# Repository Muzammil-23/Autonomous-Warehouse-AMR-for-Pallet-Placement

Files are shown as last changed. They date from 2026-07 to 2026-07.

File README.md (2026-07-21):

# Autonomous Mobile Robot with Pallet Placement System

## 📋 Project Overview

This project is a complete autonomous robot system designed for precision navigation and material handling. The robot navigates a 4×4 grid using an 8-channel QTR sensor array, detects intersections, and executes complex maneuvers including turning, obstacle detection, and automated pallet placement.

Developed for National Engineering and Robotics Contest (NERC) in 2026, this robot demonstrates:
- Autonomous navigation on grid-based paths
- Precision obstacle detection and avoidance
- Automated pallet placement using color sensing

### 🎯 Key Capabilities

- **Autonomous Navigation:** PID-controlled line following with intersection detection
- **Grid Navigation:** Navigates through intersections with specific turn logic
- **Obstacle Detection:** Ultrasonic sensor for rack detection and collision avoidance
- **Pallet Mechanism:** Servo-controlled pushing/retracting with stepper elevator
- **Color Detection:** TCS34725 sensor for blue color identification during pallet placement
- **State Management:** Multi-phase operation with graceful transitions

## Robot Photos
| Front View | Side View | 
|---|---|
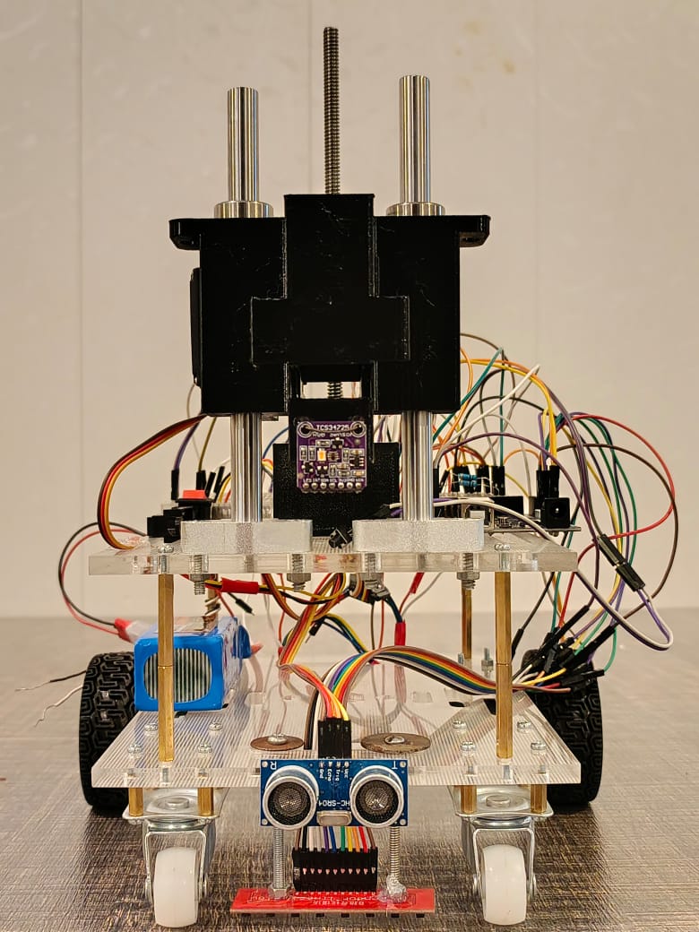
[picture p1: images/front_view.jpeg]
Front
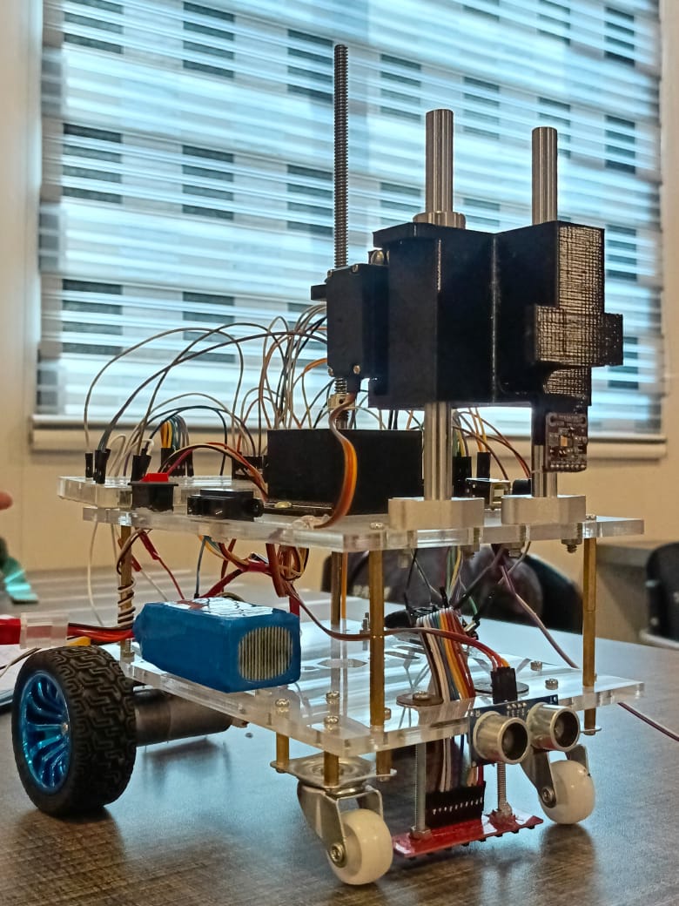
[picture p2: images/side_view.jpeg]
Side
|  |  |

### 🏗️ System Architecture
Phase 1: Grid Navigation 
Navigates the arena autonomously.

Phase 2: Rack Approach
└── Ultrasonic distance monitoring (stops at 1cm)

Phase 3: Pallet Placement
├── Elevator up while scanning for blue color
├── One full rotation after detection
├── Servo pushes pallet (CW)
├── Servo retracts (CCW)
└── Elevator lowers (5500 steps)

### 🔧 Hardware Components

| Component | Purpose | Quantity |
|---|---|---|
| Arduino Mega | Main controller | 1 |
| TB6612FNG | DC motor control | 1 |
| 2x DC Motors | Differential drive | 2 |
| 8-Channel QTR Array | Line sensing | 1 |
| HC-SR04 | Ultrasonic obstacle detection | 1 |
| TCS34725 | Color sensing (blue detection) | 1 |
| NEMA 11 | Elevator mechanism | 1 |
| MG996R | Pallet push/retract | 1 |
| Push Buttons (x2) | Calibration & Start | 2 |

## Assembled robot in SolidWorks
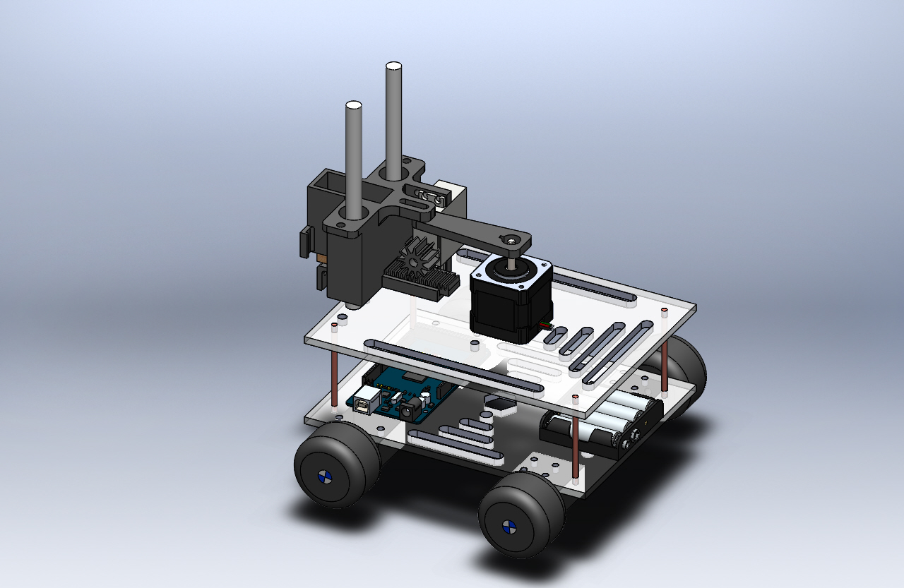
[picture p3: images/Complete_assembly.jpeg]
Assembled robot in Solidworks


### 📦 Required Libraries
```cpp
// Install these libraries from Arduino Library Manager or GitHub
#include <QTRSensors.h>          // Pololu QTR Sensors
#include <SparkFun_TB6612.h>    // TB6612 Motor Driver
#include <Wire.h>               // I2C Communication
#include <Adafruit_TCS34725.h>  // Color Sensor
#include <Servo.h>              // Servo Control

🚀 Getting Started
1. Wiring
Connect components according to the pin configuration in the code:

| Component | Pin(s) |
|-----------|--------|
| TB6612 - AIN1 | 3 |
| TB6612 - AIN2 | 4 |
| TB6612 - PWMA | 5 |
| TB6612 - BIN1 | 7 |
| TB6612 - BIN2 | 8 |
| TB6612 - PWMB | 6 |
| TB6612 - STBY | 9 |
| Ultrasonic TRIG | 18 |
| Ultrasonic ECHO | 19 |
| A4988 STEP | 13 |
| A4988 DIR | 12 |
| Servo | 44 |
| Calibrate Button | 11 |
| Start Button | 10 |
| QTR Sensors | A0-A7 |
| TCS34725 | I2C (SDA/SCL) |
| LED_BUILTIN | 13 |

2. Calibration
Place robot on the line track

Press the calibrate button (Pin 11)

Move robot back and forth over the line during calibration

Wait for LED to stop flashing

3. Running
Press the start button (Pin 10)

Robot will begin autonomous navigation

Monitor Serial Monitor for debug output (9600 baud)

📊 Performance Results

✅ 10/10 successful runs

✅ Consistent intersection detection

✅ ±1cm stopping accuracy from obstacle

✅ Consistent blue color detection and pallet placement

✅ Average completion time: 41 seconds

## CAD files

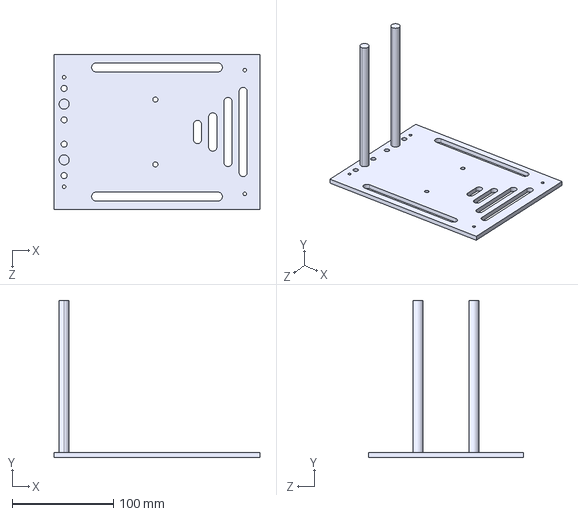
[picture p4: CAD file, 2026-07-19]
CAD Files/Upper_Base.STEP
203.2 x 155.0 x 152.4 mm

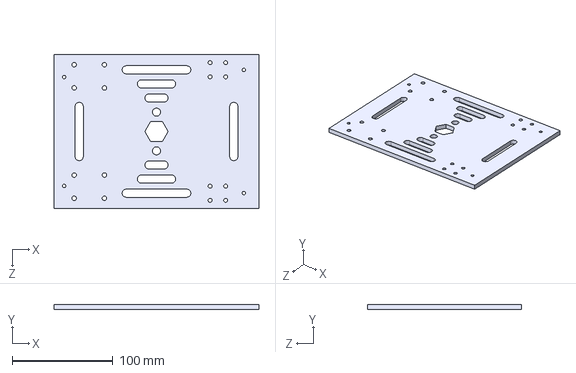
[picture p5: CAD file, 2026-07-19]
CAD Files/Lower_Base.STEP
203.2 x 5.00 x 152.4 mm

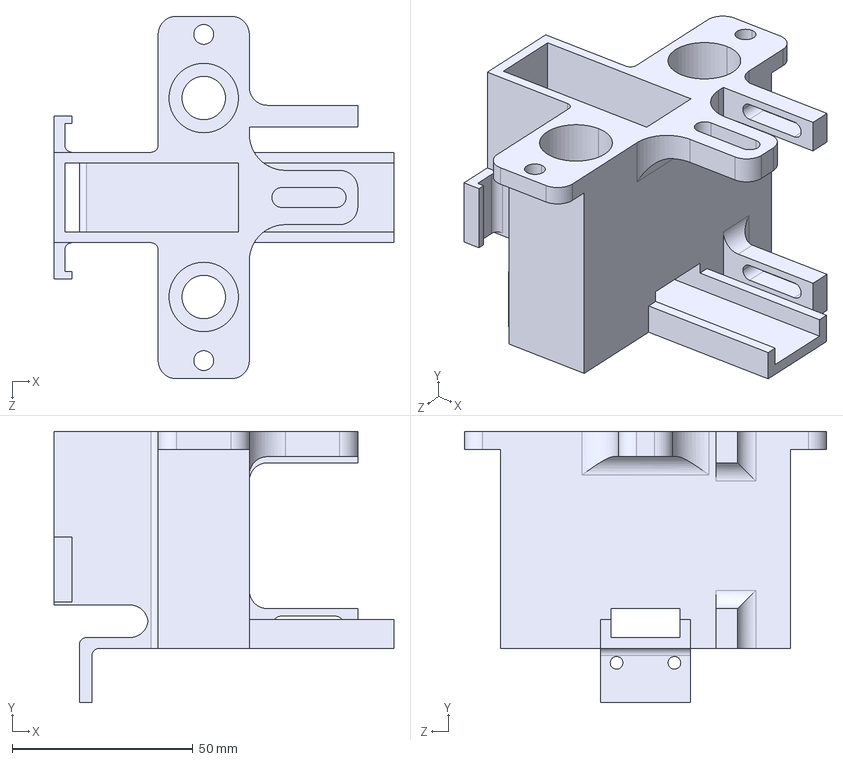
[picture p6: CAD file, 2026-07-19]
CAD Files/Lift_mechanism.STEP
94.0 x 75.0 x 100.2 mm

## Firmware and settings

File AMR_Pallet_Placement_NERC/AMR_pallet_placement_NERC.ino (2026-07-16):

#include <QTRSensors.h>
#include <SparkFun_TB6612.h>
#include <Wire.h>
#include <Adafruit_TCS34725.h>
#include <Servo.h>

// ==================== MOTOR DRIVER PINS ====================
#define AIN1 3
#define AIN2 4
#define PWMA 5
#define BIN1 7
#define BIN2 8
#define PWMB 6
#define STBY 9

// ==================== ULTRASONIC PINS ====================
#define TRIG_PIN 18
#define ECHO_PIN 19

// ==================== STEPPER PINS ====================
#define STEP_PIN 13
#define DIR_PIN 12

// ==================== SERVO PIN ====================
#define SERVO_PIN 44

// ==================== BUTTONS ====================
int buttoncalibrate = 11;
int buttonstart = 10;

// ==================== MOTOR DRIVER SETUP ====================
const int offsetA = 1;
const int offsetB = 1;
Motor motor1 = Motor(AIN1, AIN2, PWMA, offsetA, STBY);
Motor motor2 = Motor(BIN1, BIN2, PWMB, offsetB, STBY);

// ==================== QTR SENSOR ====================
QTRSensors qtr;
const uint8_t SensorCount = 8;
uint16_t sensorValues[SensorCount];

// ==================== COLOR SENSOR ====================
Adafruit_TCS34725 tcs = Adafruit_TCS34725(TCS34725_INTEGRATIONTIME_50MS, TCS34725_GAIN_4X);

// ==================== SERVO ====================
Servo palletServo;
#define SERVO_STOP 1500
#define SERVO_CW   1000
#define SERVO_CCW  2000
#define SERVO_TIME 1700

// ==================== STEPPER ====================
#define STEP_DELAY 350
#define STEP_CHECK 50
const int STEPS_PER_REVOLUTION = 200;

// ==================== PID ====================
float Kp = 0.3;
float Kd = 1.5;
int basespeed = 70;
int turnspeed = 30;
int maxspeed = 80;
int lastError = 0;
int lastDirection = 1;

// ==================== NAVIGATION STATE ====================
int intersectionCount = 0;
boolean atIntersectionFlag = false;
boolean navigationDone = false;
boolean isTurning = false;
boolean lineFollowingActive = true;
boolean rackReached = false;

// ==================== PALLET STATE ====================
boolean blueDetected = false;
boolean finalRotationComplete = false;
boolean loweringComplete = false;
boolean palletCycleComplete = false;
int stepsInFinalRotation = 0;
int stepsInLowering = 0;
int stepCounter = 0;

void setup() {
  Serial.begin(9600);

  // Ultrasonic
  pinMode(TRIG_PIN, OUTPUT);
  pinMode(ECHO_PIN, INPUT);

  // Stepper
  pinMode(STEP_PIN, OUTPUT);
  pinMode(DIR_PIN, OUTPUT);
  digitalWrite(DIR_PIN, LOW); // LOW = UP

  // Servo
  palletServo.attach(SERVO_PIN);
  palletServo.writeMicroseconds(SERVO_STOP);

  // QTR
  qtr.setTypeAnalog();
  qtr.setSensorPins((const uint8_t[]){A0, A1, A2, A3, A4, A5, A6, A7}, SensorCount);
  qtr.setEmitterPin(2);

  // Color sensor
  if (tcs.begin()) {
    Serial.println("TCS34725 ready");
  } else {
    Serial.println("TCS34725 not found!");
    while (1);
  }

  delay(500);
  pinMode(LED_BUILTIN, OUTPUT);
  pinMode(buttoncalibrate, INPUT);
  pinMode(buttonstart, INPUT);

  // Calibrate
  while (digitalRead(buttoncalibrate) == LOW) {}
  digitalWrite(LED_BUILTIN, HIGH);
  for (uint16_t i = 0; i < 400; i++) {
    qtr.calibrate();
  }
  digitalWrite(LED_BUILTIN, LOW);

  brake(motor1, motor2);

  // Wait for start
  while (digitalRead(buttonstart) == LOW) {}
  delay(1000);
  Serial.println("Starting!");
}

// ==================== ULTRASONIC ====================
float getDistance() {
  digitalWrite(TRIG_PIN, LOW);
  delayMicroseconds(2);
  digitalWrite(TRIG_PIN, HIGH);
  delayMicroseconds(10);
  digitalWrite(TRIG_PIN, LOW);
  long duration = pulseIn(ECHO_PIN, HIGH, 30000);
  if (duration == 0) return 999;
  return duration * 0.0343 / 2;
}

// ==================== LINE FOLLOWING ====================
boolean atIntersection() {
  return (sensorValues[0] > 700 && sensorValues[1] > 700 &&
          sensorValues[6] > 700 && sensorValues[7] > 700);
}

boolean lineLost() {
  for (int i = 0; i < SensorCount; i++) {
    if (sensorValues[i] > 600) return false;
  }
  return true;
}

boolean approachingTurn() {
  boolean leftEdge = (sensorValues[0] > 600 || sensorValues[1] > 600);
  boolean rightEdge = (sensorValues[6] > 600 || sensorValues[7] > 600);
  boolean middleClear = (sensorValues[3] < 300 && sensorValues[4] < 300);
  return (leftEdge || rightEdge) && middleClear;
}

void followLine() {
  uint16_t position = qtr.readLineBlack(sensorValues);
  int error = position - 3500;

  if (error < -500) lastDirection = -1;
  if (error > 500) lastDirection = 1;

  int D = error - lastError;
  lastError = error;

  int motorspeed = (error * Kp) + (D * Kd);
  int currentBasespeed = approachingTurn() ? turnspeed : basespeed;

  int motorspeeda = currentBasespeed + motorspeed;
  int motorspeedb = currentBasespeed - motorspeed;

  if (motorspeeda > maxspeed) motorspeeda = maxspeed;
  if (motorspeedb > maxspeed) motorspeedb = maxspeed;
  if (motorspeeda < 0) motorspeeda = 0;
  if (motorspeedb < 0) motorspeedb = 0;

  motor1.drive(motorspeeda);
  motor2.drive(motorspeedb);
}

void recoverLine() {
  if (lastDirection == 1) {
    motor1.drive(40);
    motor2.drive(-40);
  } else {
    motor1.drive(-40);
    motor2.drive(40);
  }

  unsigned long startTime = millis();
  while (millis() - startTime < 1000) {
    qtr.readLineBlack(sensorValues);
    if (sensorValues[3] > 600 || sensorValues[4] > 600) {
      brake(motor1, motor2);
      delay(50);
      return;
    }
  }
  brake(motor1, motor2);
}

// ==================== TURNS ====================
void turnRight() {
  Serial.println("Turning right");
  isTurning = true;
  lineFollowingActive = false;
  brake(motor1, motor2);
  delay(200);
  motor1.drive(-80);
  motor2.drive(80);
  delay(500);
  brake(motor1, motor2);
  delay(200);
  isTurning = false;
  lineFollowingActive = true;
}

void turnLeft() {
  Serial.println("Turning left");
  isTurning = true;
  lineFollowingActive = false;
  brake(motor1, motor2);
  delay(200);
  motor1.drive(80);
  motor2.drive(-80);
  delay(600);
  brake(motor1, motor2);
  delay(200);
  isTurning = false;
  lineFollowingActive = true;
}

void goStraight() {
  motor1.drive(50);
  motor2.drive(50);
  delay(350);
  brake(motor1, motor2);
  delay(100);
}

// ==================== INTERSECTION HANDLING ====================
void handleIntersection() {
  intersectionCount++;
  Serial.print("Intersection: ");
  Serial.println(intersectionCount);

  if (intersectionCount == 1 || intersectionCount == 2) {
    goStraight();
  } else if (intersectionCount == 3) {
    turnRight();
  } else if (intersectionCount == 4) {
    goStraight();
  } else if (intersectionCount == 5) {
    turnLeft();
    navigationDone = true;
    Serial.println("Navigation done — approaching rack");
  }
}

// ==================== PALLET CYCLE ====================
void runPalletCycle() {
  Serial.println("Starting pallet cycle");

  // Phase 1 + 2: Move up until blue detected then 1 extra rotation
  digitalWrite(DIR_PIN, LOW); // UP
  blueDetected = false;
  finalRotationComplete = false;
  stepsInFinalRotation = 0;
  stepCounter = 0;

  while (!finalRotationComplete) {
    digitalWrite(STEP_PIN, HIGH);
    delayMicroseconds(STEP_DELAY);
    digitalWrite(STEP_PIN, LOW);
    delayMicroseconds(STEP_DELAY);

    if (!blueDetected) {
      stepCounter++;
      if (stepCounter >= STEP_CHECK) {
        stepCounter = 0;
        float r, g, b;
        tcs.getRGB(&r, &g, &b);
        if (b > r && b > g) {
          Serial.println("Blue detected!");
          blueDetected = true;
          stepsInFinalRotation = 0;
        }
      }
    } else {
      stepsInFinalRotation++;
      if (stepsInFinalRotation >= STEPS_PER_REVOLUTION) {
        finalRotationComplete = true;
      }
    }
  }

  Serial.println("At target slot");

  // Push pallet
  Serial.println("Pushing pallet");
  palletServo.writeMicroseconds(SERVO_CW);
  delay(SERVO_TIME);
  palletServo.writeMicroseconds(SERVO_STOP);

  delay(500);

  // Retract
  Serial.println("Retracting");
  palletServo.writeMicroseconds(SERVO_CCW);
  delay(SERVO_TIME);
  palletServo.writeMicroseconds(SERVO_STOP);

  Serial.println("Pallet placed");

  // Phase 3: Lower elevator
  Serial.println("Lowering elevator");
  digitalWrite(DIR_PIN, HIGH); // DOWN
  stepsInLowering = 0;
  while (stepsInLowering < 5500) {
    digitalWrite(STEP_PIN, HIGH);
    delayMicroseconds(STEP_DELAY);
    digitalWrite(STEP_PIN, LOW);
    delayMicroseconds(STEP_DELAY);
    stepsInLowering++;
  }

  Serial.println("Elevator lowered");
  palletCycleComplete = true;
}

// ==================== MAIN LOOP ====================
void loop() {
  // Phase 4 — everything done
  if (palletCycleComplete) {
    brake(motor1, motor2);
    return;
  }

  // Phase 3 — rack reached, run pallet cycle
  if (rackReached) {
    runPalletCycle();
    return;
  }

  // Phase 2 — navigation done, approach rack at full speed
  if (navigationDone) {
    float distance = getDistance();
    Serial.print("Distance: ");
    Serial.println(distance);

    if (distance > 0 && distance <= 2.0) {
      Serial.println("Rack reached — stopping");
      brake(motor1, motor2);
      delay(200);
      rackReached = true;
      return;
    }

    // Follow line at full speed toward rack
    qtr.readLineBlack(sensorValues);
    if (lineLost()) {
      recoverLine();
      return;
    }
    followLine();
    return;
  }

  // Phase 1 — grid navigation
  if (!isTurning && lineFollowingActive) {
    qtr.readLineBlack(sensorValues);

    boolean intersection = atIntersection();
    if (intersection && !atIntersectionFlag) {
      atIntersectionFlag = true;
      handleIntersection();
      return;
    } else if (!intersection) {
      atIntersectionFlag = false;
    }

    if (lineLost()) {
      recoverLine();
      return;
    }

    followLine();
  }
}
